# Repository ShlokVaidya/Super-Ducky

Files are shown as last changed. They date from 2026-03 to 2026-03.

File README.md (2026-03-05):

# Super-Ducky
# RP2350A Dual-Mode USB Device

## 1. Description

This project is a custom USB storage and control device powered by the **Raspberry Pi RP2350A** microcontroller. It serves as a dualmode device separating system firmware from user data through a high-speed eMMC interface

The system architecture utilizes a 4-layer PCB to maintain signal integrity for high-speed digital lines (USB and eMMC).

| Component | Function |
| :---- | :---- |
| **RP2350A** | Central MCU handling USB stack and storage logic |
| **eMMC (16GB)** | High density mass storage for user data |
| **QSPI Flash** | Dedicated firmware and bootloader execution |
| **LDO Regulators** | AP2112K series for stable 1.8V and 3.3V rails |
| **USB Mux** | TS3USB221 for signal routing and integrity |

## 2. Why I Built This

I built this project to explore **full stack embedded system development**.

Most beginner projects focus only on firmware or simple microcontroller boards. This project instead focuses on the **entire engineering process** including:

- **Hardware Architecture:** Designing a system that separates firmware execution (QSPI) from high-capacity storage (eMMC).
- **Advanced Sourcing:** Navigating global supply chains to source specialized ICs like the MTFC16GAKAEDQ-AIT eMMC via JLCPCB Global Sourcing.
- **High-Speed Design:** Learning to route differential USB pairs and high-clock-rate storage interfaces on a multi-layer board.
- **Power Management:** Implementing a multi-rail (3.3V/1.8V) system to satisfy different logic level requirements.

The goal was to move beyond hobbyist "breadboarding" and understand how professional-grade embedded products are engineered from the ground up.

## 3. How to Use the Device

1. **Connection:** Connect the device to a computer using a standard USB-C cable.
2. **Standard Operation:** The RP2350A initializes, loads firmware from the QSPI flash, and mounts the eMMC as a storage drive or serial device depending on the firmware configuration.
3. **Boot Selection:** To update firmware or change modes, hold the **Boot Button (GPIO22)** while plugging in the device. This forces the RP2350A into its native USB bootloader mode.
4. **Data Access:** Once connected, the host computer interacts with the 16GB eMMC through the high-speed USB interface managed by the MCU.

## 4. Hardware Visualization

### Full Schematic

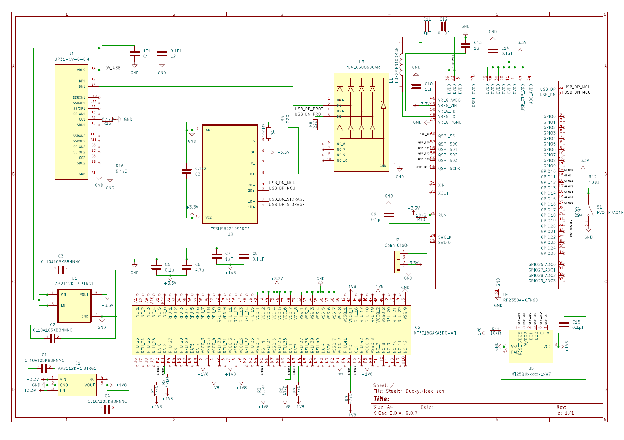
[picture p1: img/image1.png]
Full Schematic


### PCB Layout

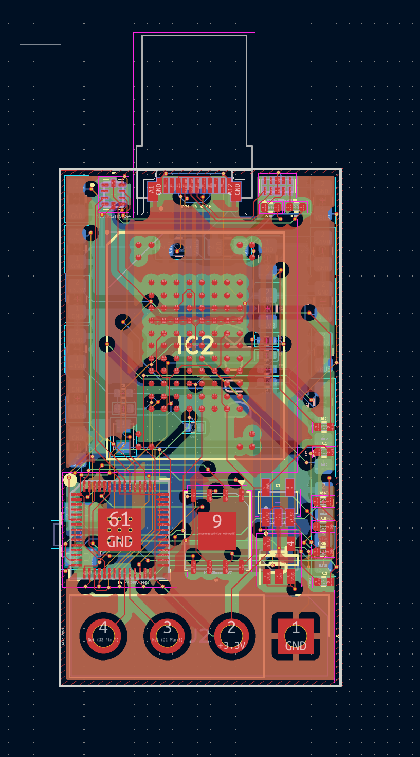
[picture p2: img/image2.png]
PCB Layout


### 3D Render

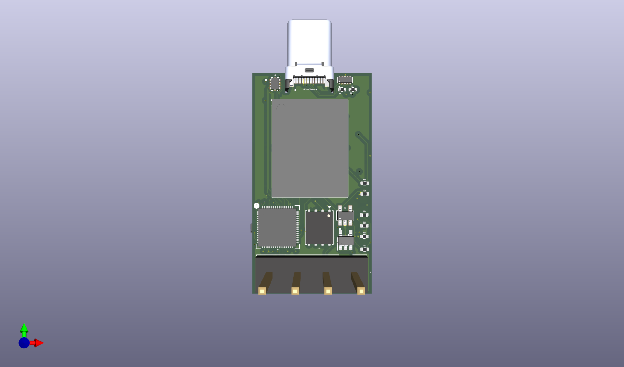
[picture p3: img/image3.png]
3D Render 1

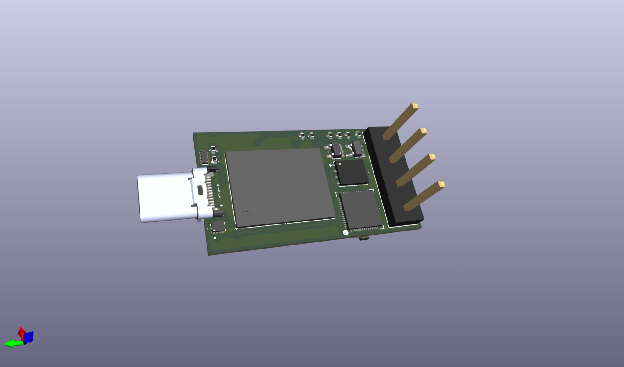
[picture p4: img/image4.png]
3D Render 2

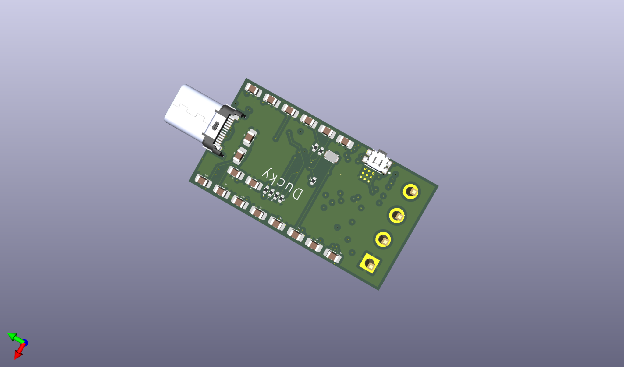
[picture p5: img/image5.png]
3D Render 3

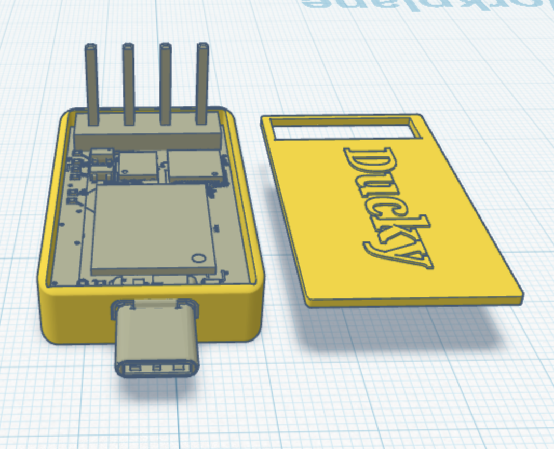
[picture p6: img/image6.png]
3D Render 4


### BOM

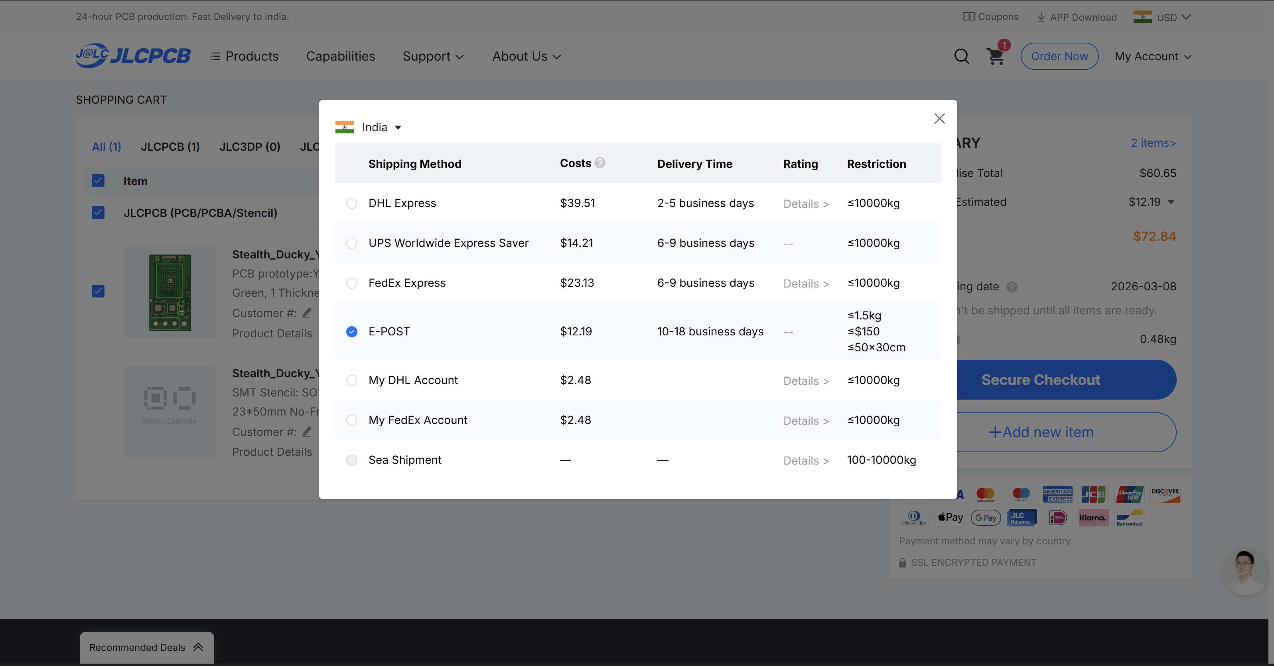
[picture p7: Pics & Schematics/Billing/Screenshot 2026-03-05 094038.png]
JLCPCB

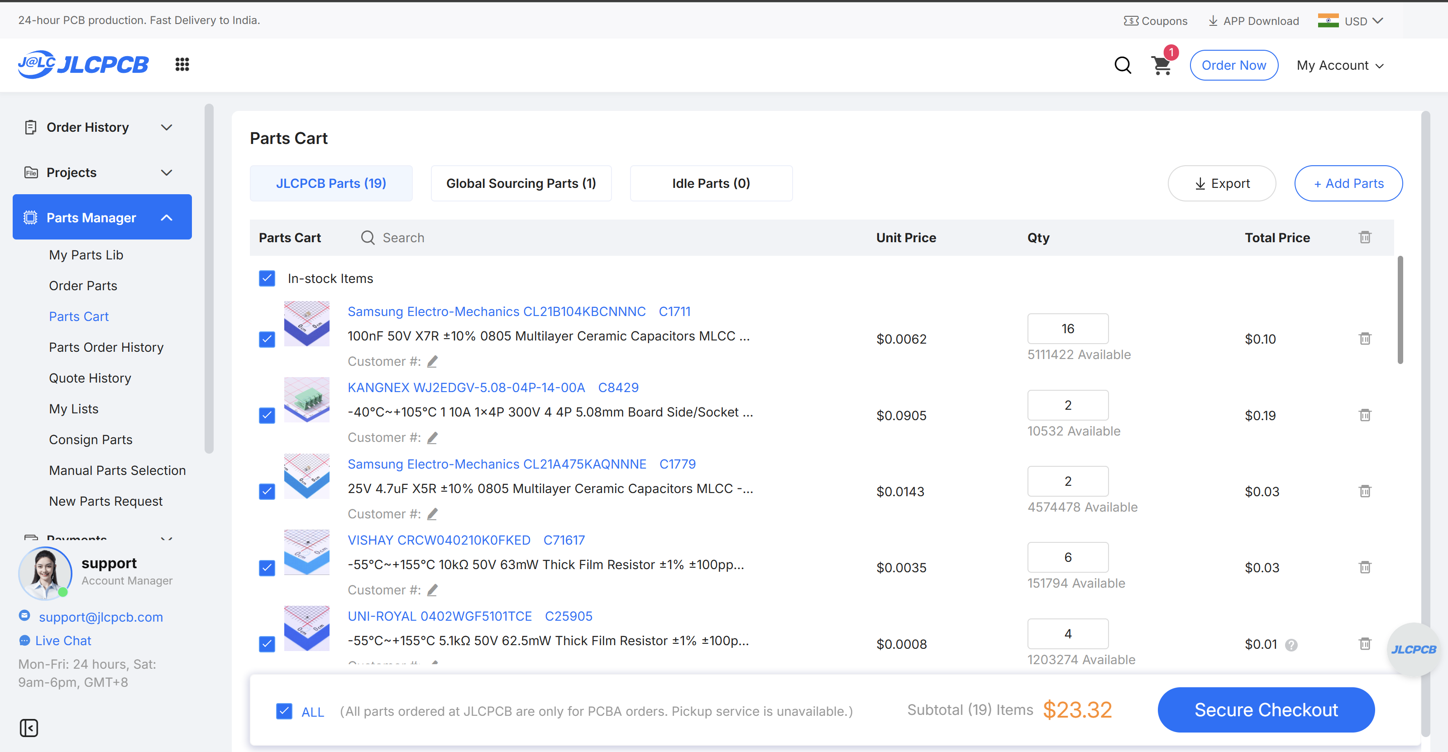
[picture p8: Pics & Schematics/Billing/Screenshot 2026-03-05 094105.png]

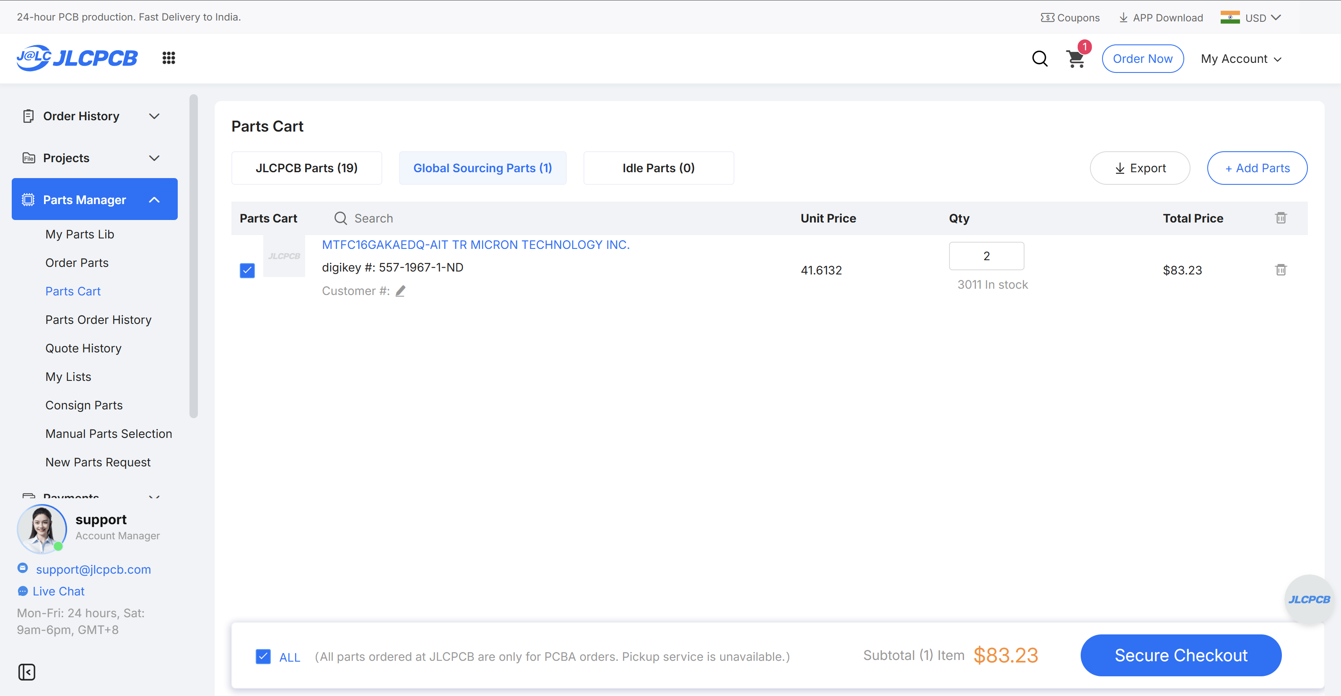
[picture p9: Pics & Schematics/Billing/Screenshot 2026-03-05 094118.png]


## 5. Bill of Materials (BOM)

The following table lists all 20 parts required for the assembly, consolidated from the design files and JLCPCB procurement logs.

| Parts Type | JLCPCB Part \# | MFR Part \# | Link | Description | Unit Price | Qty | Total Price |
| :---- | :---- | :---- | :---- | :---- | :---- | :---- | :---- |
| stock | C1711 | CL21B104KBCNNNC | https://jlcpcb.com/partdetail/2063-CL21B104KBCNNNC/C1711 | 100nF 50V X7R ±10% 0805 Multilayer Ceramic Capacitors MLCC \- SMD/SMT ROHS | 0.0062 | 16 | 0.1 |
| stock | C8429 | WJ2EDGV-5.08-04P-14-00A | https://jlcpcb.com/partdetail/8923-WJ2EDGV\_5\_08\_04P\_1400A/C8429 | \-40℃\~+105℃ 1 10A 1x4P 300V 4 4P 5.08mm Board Side/Socket \- Open Green Hinged (Snap On) Through Hole Plugin,P=5.08mm Pluggable System Terminal Block ROHS | 0.0905 | 2 | 0.19 |
| stock | C1779 | CL21A475KAQNNNE | https://jlcpcb.com/partdetail/2131-CL21A475KAQNNNE/C1779 | 25V 4.7uF X5R ±10% 0805 Multilayer Ceramic Capacitors MLCC \- SMD/SMT ROHS | 0.0143 | 2 | 0.03 |
| buy | C6006988 | UP31-CV-G-CM | https://jlcpcb.com/partdetail/CUI-UP31\_CV\_GCM/C6006988 | \- USB Connectors ROHS | 2.265 | 4 | 9.06 |
| stock | C71617 | CRCW040210K0FKED | https://jlcpcb.com/partdetail/VishayIntertech-CRCW040210K0FKED/C71617 | \-55℃\~+155℃ 10kΩ 50V 63mW Thick Film Resistor ±1% ±100ppm/℃ 0402 Chip Resistor \- Surface Mount ROHS | 0.0035 | 6 | 0.03 |
| buy | C100612 | CR0402JF0220G | https://jlcpcb.com/partdetail/LIZElec-CR0402JF0220G/C100612 | \-55℃\~+125℃ 22Ω 50V 62.5mW Thick Film Resistor ±200ppm/℃ ±5% 0402 Chip Resistor \- Surface Mount ROHS | 0.0003 | 10000 | 3 |
| stock | C25905 | 0402WGF5101TCE | https://jlcpcb.com/partdetail/26648-0402WGF5101TCE/C25905 | \-55℃\~+155℃ 5.1kΩ 50V 62.5mW Thick Film Resistor ±1% ±100ppm/℃ 0402 Chip Resistor \- Surface Mount ROHS | 0.0008 | 4 | 0.01 |
| stock | C25792 | 0402WGF4702TCE | https://jlcpcb.com/partdetail/26535-0402WGF4702TCE/C25792 | \-55℃\~+155℃ 47kΩ 50V 62.5mW Thick Film Resistor ±1% ±100ppm/℃ 0402 Chip Resistor \- Surface Mount ROHS | 0.0008 | 10 | 0.01 |
| stock | C25530 | 0402WGJ0104TCE | https://jlcpcb.com/partdetail/26273-0402WGJ0104TCE/C25530 | \-55℃\~+155℃ 100kΩ 50V 62.5mW Thick Film Resistor ±100ppm/℃ ±5% 0402 Chip Resistor \- Surface Mount ROHS | 0.0006 | 4 | 0.01 |
| stock | C25076 | 0402WGF1000TCE | https://jlcpcb.com/partdetail/25819-0402WGF1000TCE/C25076 | \-55℃\~+155℃ 100Ω 50V 62.5mW Thick Film Resistor ±1% ±100ppm/℃ 0402 Chip Resistor \- Surface Mount ROHS | 0.0008 | 2 | 0.01 |
| stock | C1712 | CL21B105KAFNFNE | https://jlcpcb.com/partdetail/2064-CL21B105KAFNFNE/C1712 | 1uF 25V X7R ±10% 0805 Multilayer Ceramic Capacitors MLCC \- SMD/SMT ROHS | 0.0133 | 18 | 0.24 |
| stock | C138714 | TPD4E05U06DQAR | https://jlcpcb.com/partdetail/TexasInstruments-TPD4E05U06DQAR/C138714 | \-40℃\~+125℃ 0.5pF 10nA 14V 2.5A@8/20us 4 40W@8/20us 5.5V 6.5V ESD IEC 61000-4-2、IEC 61000-4-5、IEC 61000-4-4 Unidirectional USON-10(1x2.5) ESD and Surge Protection (TVS/ESD) ROHS | 0.072 | 2 | 0.15 |
| stock | C295091 | XJHCELNANF-12MHZ | https://jlcpcb.com/partdetail/TAITIENElec-XJHCELNANF12MHZ/C295091 | \-40℃\~+85℃ 12MHz 20pF Crystal Oscillator ±30ppm ±30ppm HC-49S-SMD Crystals ROHS | 0.1385 | 2 | 0.28 |
| stock | C176944 | AP2112K-1.8TRG1 | https://jlcpcb.com/partdetail/DiodesIncorporated-AP2112K\_18TRG1/C176944 | \-40℃\~+85℃@(Ta) 1 1.8V 500mV@(600mA) 50uVrms 55uA 600mA 65dB@(1kHz) 6V Fixed Over Current Protection、Over Temperature Protection、Enable Positive SOT-25 Voltage Regulators \- Linear, Low Drop Out (LDO) Regulators ROHS | 0.1103 | 2 | 0.23 |
| stock | C128396 | TS3USB221ARSER | https://jlcpcb.com/partdetail/TexasInstruments-TS3USB221ARSER/C128396 | \-40℃\~+85℃ 12ns 2.3V\~3.6V 250ps 2:1 30ns 6pF 6Ω 900MHz USB UQFN-10(1.5x2) Analog Switches \- Special Purpose ROHS | 0.2515 | 2 | 0.51 |
| stock | C79167 | EVQP7A01P | https://jlcpcb.com/partdetail/PANASONIC-EVQP7A01P/C79167 | \-20℃\~+70℃ 1.35mm 100,000 cycles 12V 2.2N 3.55mm 3.5mm 50mA PC Pin Rectangular Button SPST Surface Mount, Right Angle SMD,3.6x3.5mm Tactile Switches ROHS | 0.1539 | 2 | 0.31 |
| stock | C42411118 | RP2350A | https://jlcpcb.com/partdetail/RaspberryPi-RP2350A/C42411118 | QFN-60-EP Microcontrollers (MCU/MPU/SOC) ROHS | 1.2406 | 2 | 2.49 |
| stock | C2613930 | W25Q128JVSIM | https://jlcpcb.com/partdetail/WinbondElec-W25Q128JVSIM/C2613930 | \-40℃\~+85℃ 100,000 cycles 10uA 128Mbit 133MHz 150ms@(64KB) 2.7V\~3.6V 20 Years 400us SPI SOIC-8-208mil NOR FLASH ROHS | 3.2212 | 2 | 6.45 |
| stock | C23380830 | AP2112K-3.3TRG1 | https://jlcpcb.com/partdetail/TECHPUBLIC-AP2112K\_33TRG1/C23380830 | \-40℃\~+85℃@(Ta) 1 10uA 3.3V 320mV@(600mA) 5.5V 600mA 75dB@(1kHz) Fixed Over Temperature Protection Positive SOT-23-5 Voltage Regulators \- Linear, Low Drop Out (LDO) Regulators ROHS | 0.1029 | 2 | 0.21 |

| Parts Type | JLCPCB Part \# | Digikey-ID | MFR Part \# | Description | Unit Price | Qty | Total Price |
| :---- | :---- | :---- | :---- | :---- | :---- | :---- | :---- |
| overseas\_shop | C30839157 | digikey \#: 557-1967-1-ND | MTFC16GAKAEDQ-AIT TR | IC FLASH 128GBIT MMC 100LBGA | 41.6132 | 2 | 83.23 |
***

## 6. Billing Summary

Total expenditure for PCB fabrication, assembly, and parts based on project records.

| Category | Cost (INR) | Cost (USD) |
| :---- | :---- | :---- |
| **JLCPCB Assembly (PCBA)** | ₹6,621.82 | $72.84 |
| **Component Sourcing (Global \+ Stock)** | ₹9686.36 | $106.55 |
| **Grand Total** | **₹16308.18** | **$179.39** |

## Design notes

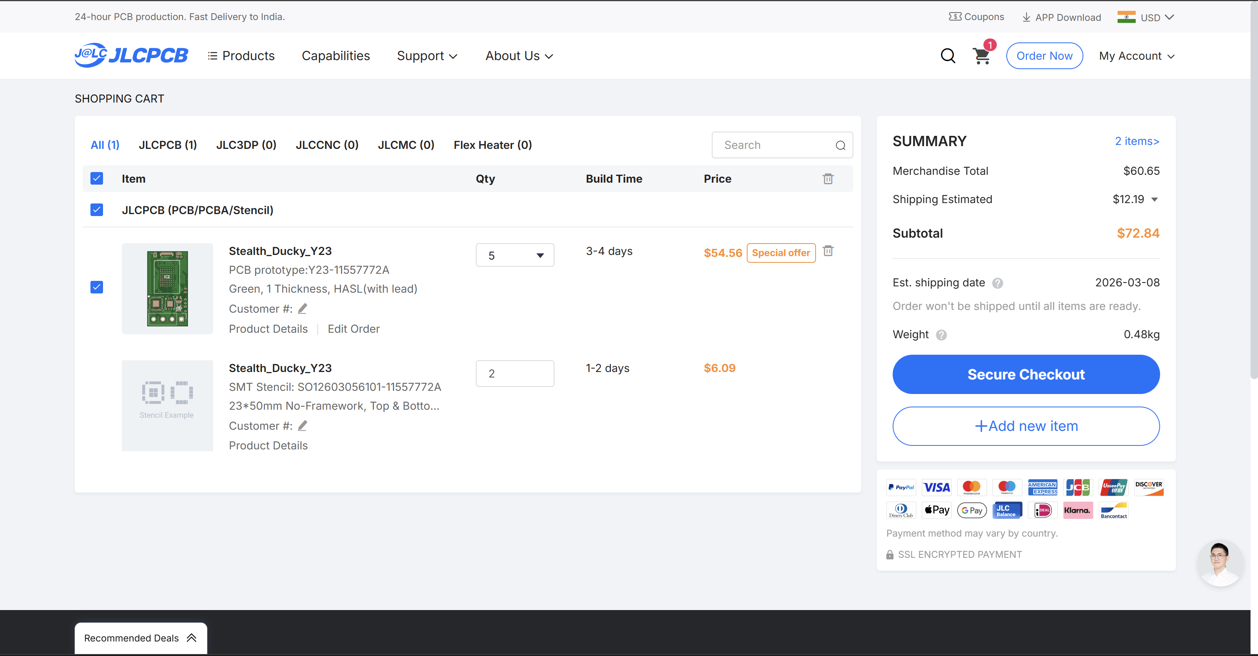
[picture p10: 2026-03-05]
Pics & Schematics/Billing/Screenshot 2026-03-05 094011.png

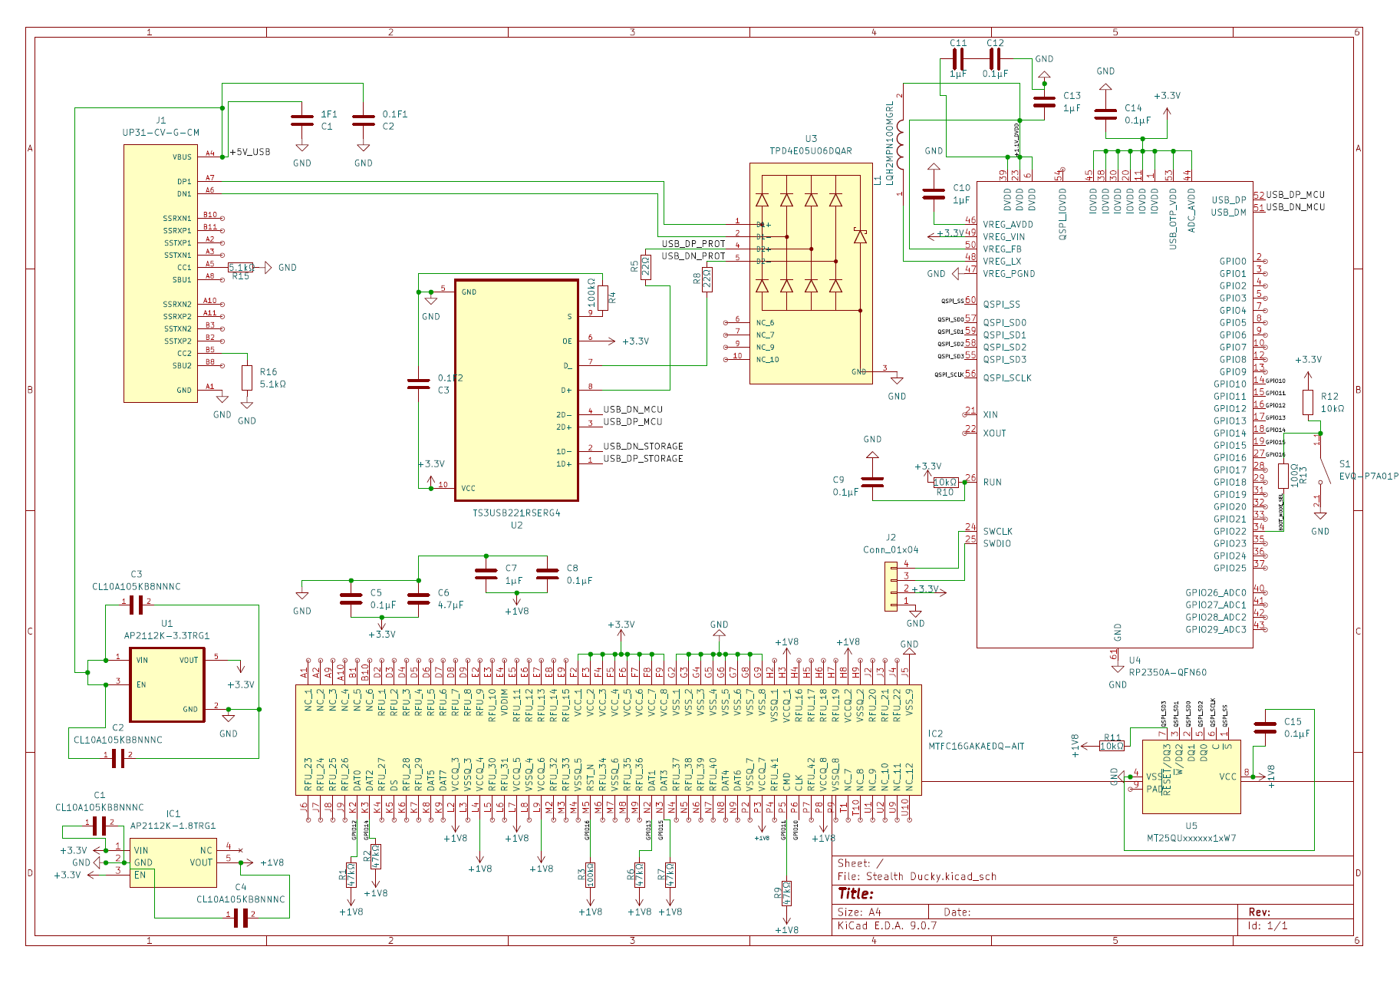
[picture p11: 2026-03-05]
Pics & Schematics/Screenshot 2026-03-05 101711.png

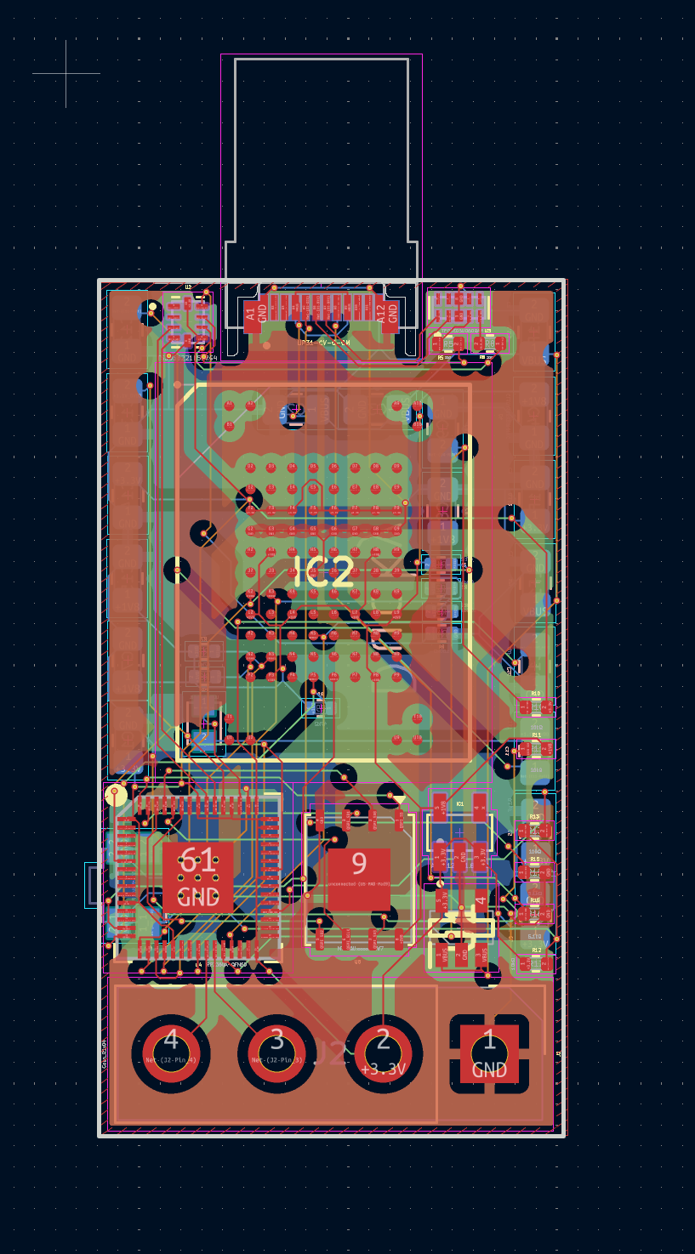
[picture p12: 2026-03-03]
Pics & Schematics/Screenshot 2026-03-02 213854.png

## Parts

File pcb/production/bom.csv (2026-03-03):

Designator | Footprint | Quantity | Value | LCSC Part #
0.1F1 | 0805 | 1 | C2 |  | 5
0.1F2 | 0805 | 1 | C3 |  | 5
1F1 | 0805 | 1 | C1 |  | 5
C1, C2, C3, C4 | 0805 | 4 | CL10A105KB8NNNC |  | 20
C10, C11, C13, C7 | 0805 | 4 | 1µF |  | 20
C12, C14, C15, C5, C8, C9 | 0805 | 6 | 0.1µF |  | 30
C6 | 0805 | 1 | 4.7µF |  | 5
IC1 | SOT95P285X140-5N | 1 | AP2112K-1.8TRG1 |  | 2
IC2 | BGA100C100P10X17_1400X1800X140 | 1 | MTFC16GAKAEDQ-AIT |  | 2
J1 | CUI_UP31-CV-G-CM | 1 | UP31-CV-G-CM |  | 2
J2 | Samtec_HPM-04-01-x-S_Straight_1x04_Pitch5.08mm | 1 | Conn_01x04 |  | 2
L1 | IND_LQH2MPN100MGRL | 1 | LQH2MPN100MGRL |  | 2
R1, R2, R6, R7, R9 | 0402 | 5 | 47kΩ |  | 10
R10, R11, R12 | 0402 | 3 | 10kΩ |  | 6
R13 | 0402 | 1 | 100Ω |  | 2
R15, R16 | 0402 | 2 | 5.1kΩ |  | 4
R3, R4 | 0402 | 2 | 100kΩ |  | 4
R5, R8 | 0402 | 2 | 22Ω |  | 4
S1 | SW_EVQ-P7A01P | 1 | EVQ-P7A01P |  | 2
U1 | SOT95P285X140-5N (2) | 1 | AP2112K-3.3TRG1 |  | 2
U2 | IC_TPD6E001RSER | 1 | TS3USB221RSERG4 |  | 2
U3 | IC_TPD4E05U06DQAR | 1 | TPD4E05U06DQAR |  | 2
U4 | RP2350A_QFN-60_EP_7.75x7.75_Pitch0.4mm | 1 | RP2350A-QFN60 |  | 2
U5 | W-PDFN-8-1EP_6x5mm_P1.27mm_EP3x3mm | 1 | MT25QUxxxxxx1xW7 |  | 2

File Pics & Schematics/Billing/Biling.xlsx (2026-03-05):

Vendor | Price (IN RUPPES) | Price ( IN DOLLARS)
JLCPCBA | 6621.818182 | 72.84
JLC COMPONENTS | 9686.363636 | 106.55
TOTAL |  | 179.39

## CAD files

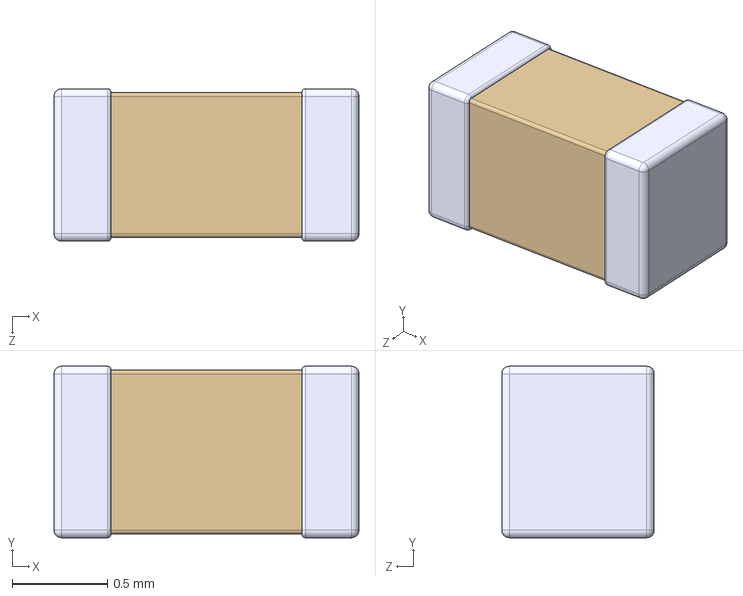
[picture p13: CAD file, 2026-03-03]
3dmodels/CL10A105KB8NNNC.step
1.60 x 0.9 x 0.8 mm

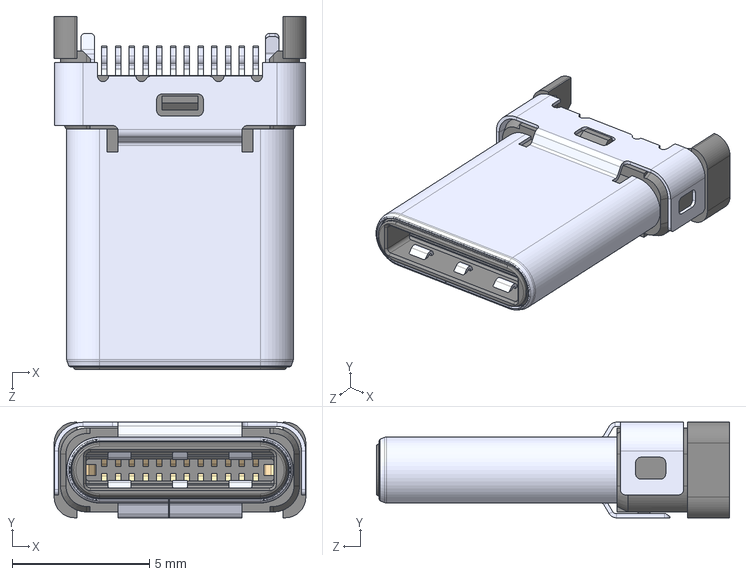
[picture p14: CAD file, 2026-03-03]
3dmodels/UP31-CV-G-CM.step
9.16 x 3.48 x 12.8 mm

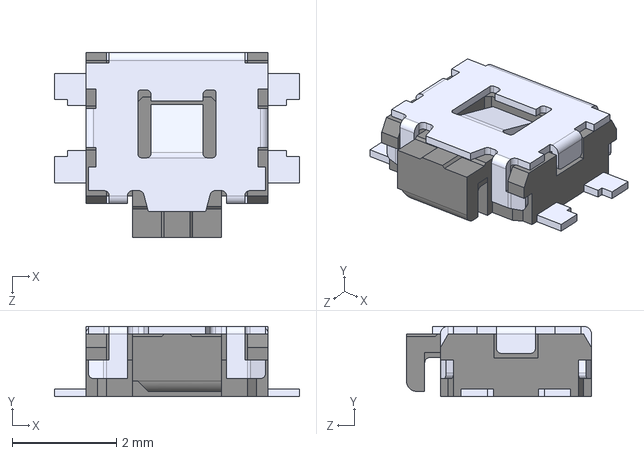
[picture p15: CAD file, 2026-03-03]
3dmodels/EVQ-P7A01P.step
4.70 x 1.35 x 3.55 mm

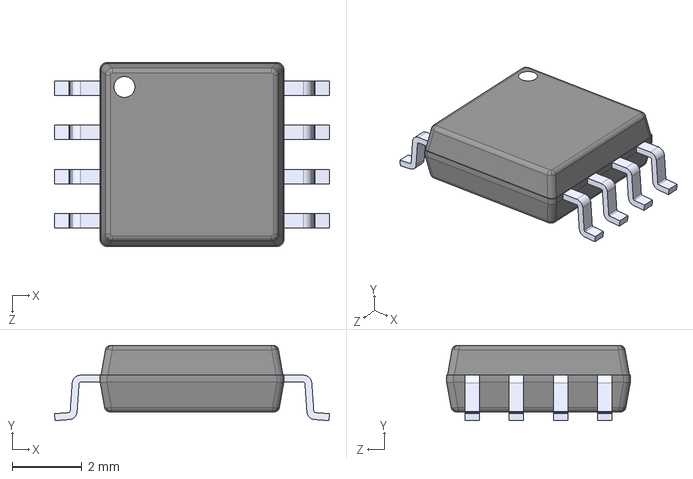
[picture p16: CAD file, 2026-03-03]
3dmodels/W25Q128JVSIM_TR.step
7.90 x 2.16 x 5.28 mm

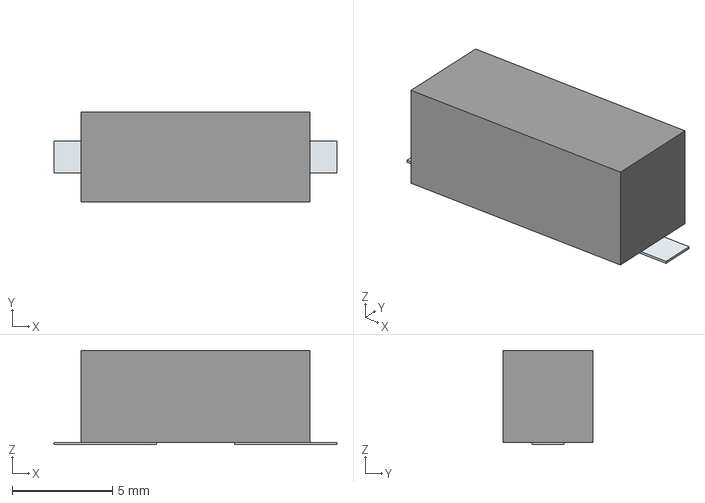
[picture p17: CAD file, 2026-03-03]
3dmodels/XJHCELNANF-12MHZ.stp
14.1 x 4.50 x 4.70 mm
Pins

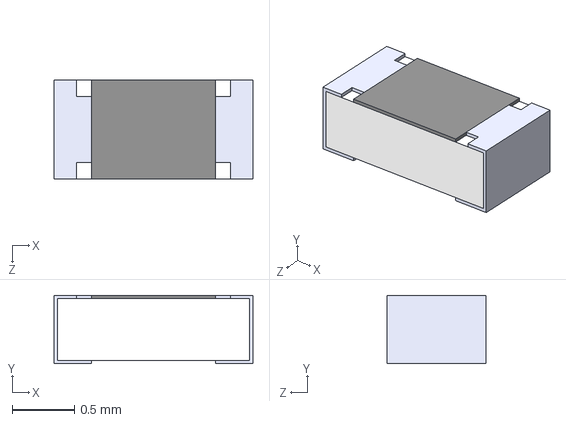
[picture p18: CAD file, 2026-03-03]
3dmodels/0603WAF1002T5E.step
1.60 x 0.55 x 0.8 mm

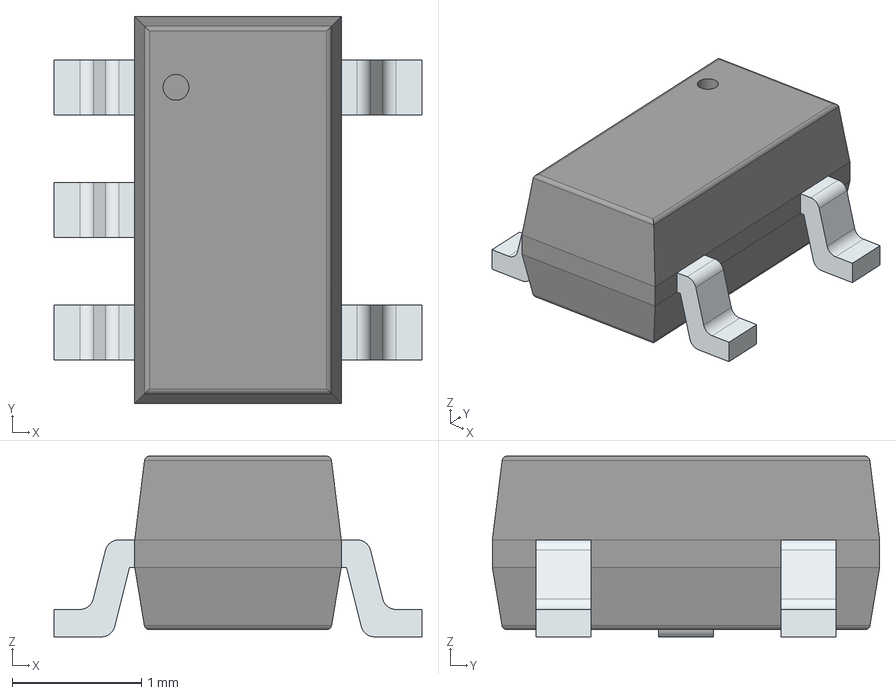
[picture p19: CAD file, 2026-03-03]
3dmodels/AP2112K-1.8TRG1.stp
2.85 x 3.00 x 1.40 mm
PinsArrayL
PinsArrayR

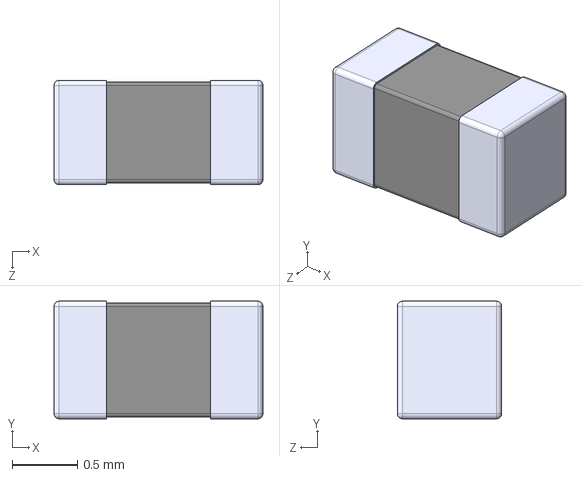
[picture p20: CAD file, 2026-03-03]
3dmodels/CC0603KRX7R9BB104.step
1.60 x 0.9 x 0.8 mm

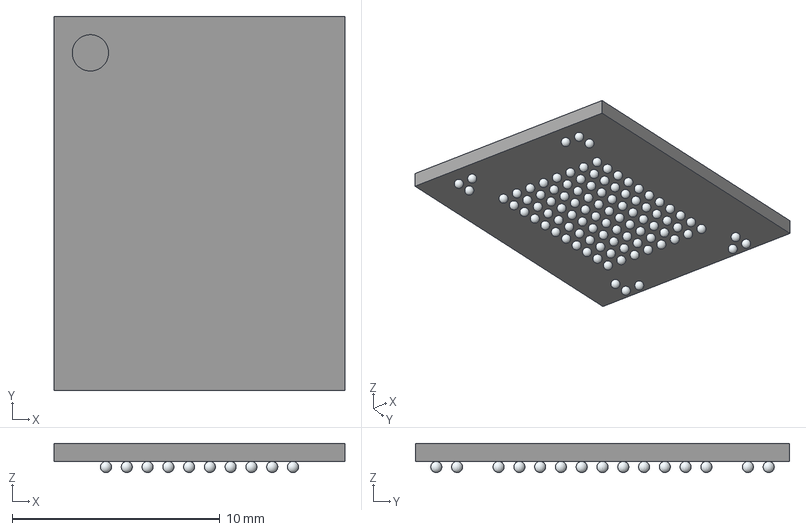
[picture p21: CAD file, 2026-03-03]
3dmodels/MTFC16GAKAEDQ-AIT.stp
14.0 x 18.0 x 1.40 mm
A1
A2
A9
A10
B1
B10
D2
D3
D4
D5
D6
D7
D8
D9
E2
E3
E4
E5
E6
E7
E8
E9
F2
F3
F4
F5
F6
F7
F8
F9
G2
G3
G4
G5
G6
G7
G8
G9
H2
H3
H4
H5
H6
H7
H8
H9
J2
J3
J4
J5
J6
J7
J8
J9
K2
K3
K4
K5
K6
K7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

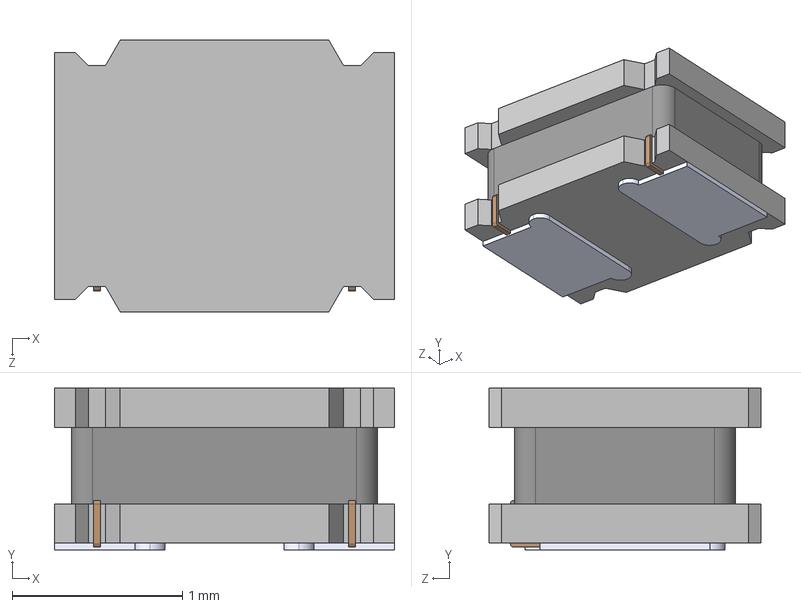
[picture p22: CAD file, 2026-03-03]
3dmodels/LQH2MPN100MGRL.step
2.00 x 0.95 x 1.60 mm

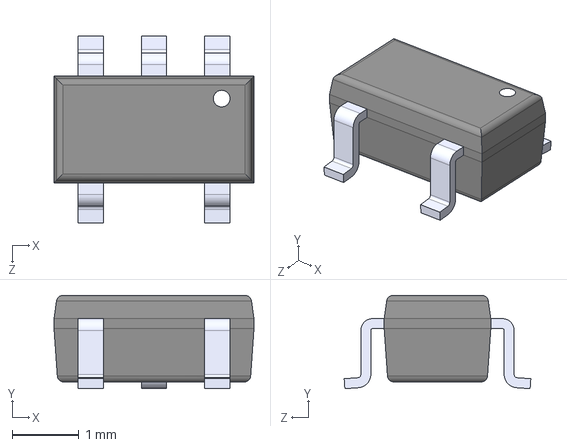
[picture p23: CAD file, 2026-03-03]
3dmodels/AP2112K-3.3TRG1.step
3.00 x 1.40 x 2.80 mm

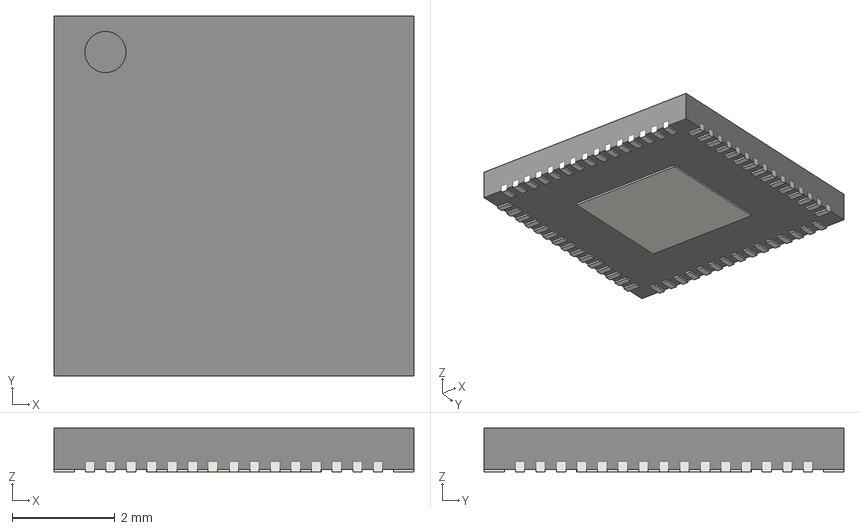
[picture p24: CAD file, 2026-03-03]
3dmodels/RP2350A-QFN60.step
7.00 x 7.00 x 0.85 mm

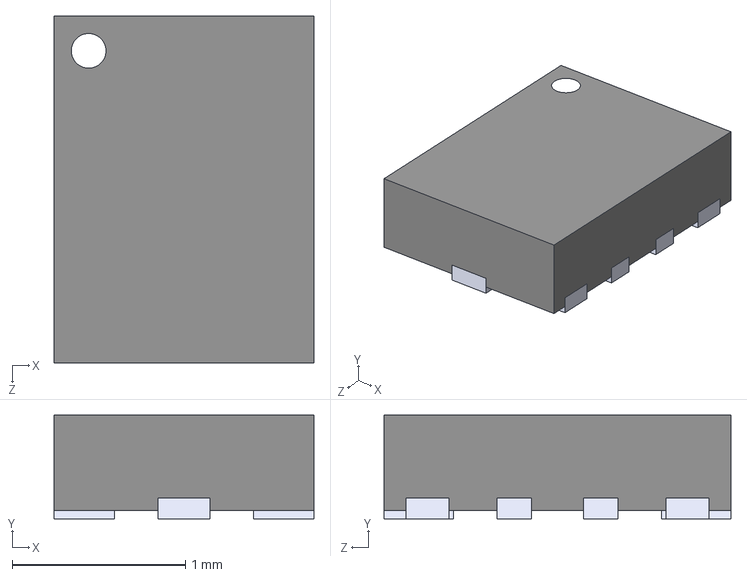
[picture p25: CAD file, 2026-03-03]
3dmodels/TS3USB221RSERG4.step
1.50 x 0.6 x 2.00 mm

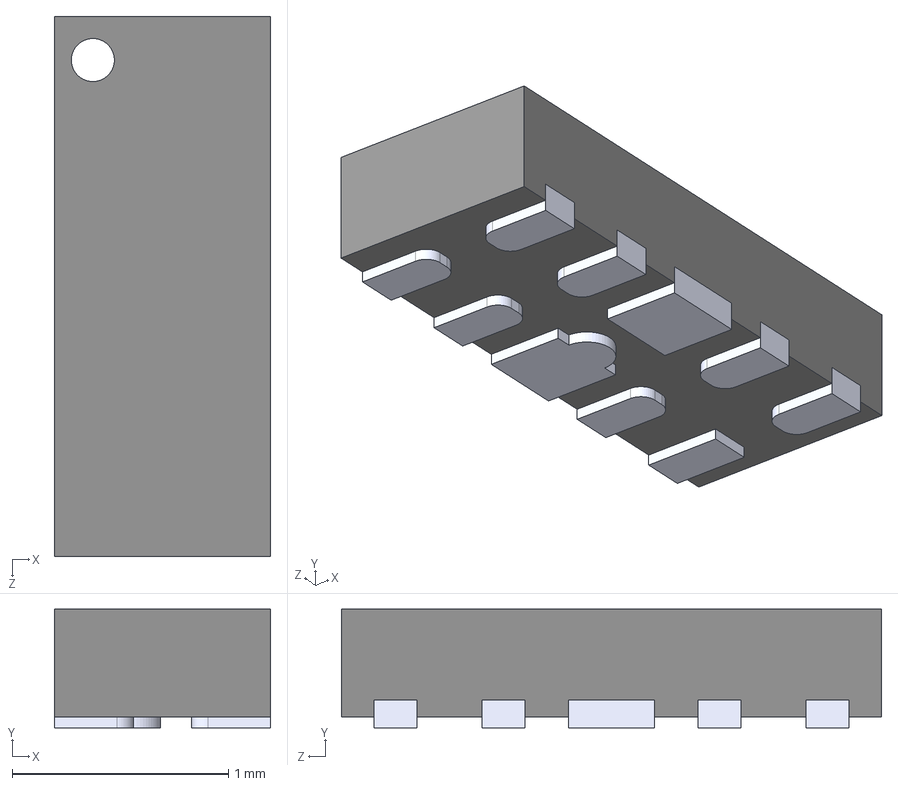
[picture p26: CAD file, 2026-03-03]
3dmodels/TPD4E05U06DQAR.step
1.00 x 0.55 x 2.50 mm

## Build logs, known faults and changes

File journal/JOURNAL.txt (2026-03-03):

day one stuff

so the project is about making a custom RP2350A dual-mode USB device with native eMMC storage. First thing i had to do was figure out the memry architecure cause the RP2350A actually needs external flash to run firmware. i looked at option A which was using just one QSPI flash for everything but i rejected it.
      Option B was a split architecure where QSPI flash is for firmware and eMMC is for mass storage, and i picked this cause its a professional pattern where firmware stays isolated. Then i had to plan the voltage domains which was super critical.
  The core is 1.1V and eMMC uses 3.3V for VCC and 1.8V for VCCQ in high speed mode. This meant i needed a separate 1.8V LDO and careful routing. If I accidentaly connected 3.3V to the 1.8V flash IOVDD it would permantly destroy the flash. ChatGPT helped me validate this huge risk.
        For the USB interface i chose USB-C for modern compatiblity and it needs 5.1kΩ pull-down resistors on CC1 and CC2. ChatGPT confirmed i need independent CC resistors and def shouldn't short them together. A critical realiztion was that the RP2350A does NOT have an SDMMC peripherel.
That means i gotta implement the MMC protocol via PIO and use a 4-bit data bus and handle the initialization sequence. This totally changed the project from just hardware into hardware and low-level firmware engineering. For power i chose AP2112K LDOs for 3.3V and 1.8V cause they have low noise and are simple to implement.

day to: scematics

Moving on to schematic design, the RP2350 internal SMPS needed an external inductor. Originally I picked a 10µH inductor but it got flagged later that the recommended value is lower. If the inductor is too large it causes poor transient response and instability. So yeah, that got corrected.
   My decoupling stratgy was putting a 0.1µF local capacitor and a 4.7µF bulk capacitor to minimize ground bounce and voltage droop. I made sure the QSPI flash IOVDD was only tied to 1.8V. For the eMMC wiring i connected CMD, CLK, and DAT0-DAT3 and added pull-ups because MMC requires a defined bus state.
         ChatGPT confirmed my bus termination approach was right. For USB protection I added TPD4E05 ESD protection and made a critical note to not create stubs before the ESD. I also designed a boot mode button with a 10k pull-up to 3.3V connected to GPIO22. Even though internal pull-ups exist, a hardware pull-up is way safer for a stable boot mode. This basically ensures deterministic boot selection at reset.

third day pcb

      For the layer stack I chose a 4-layer setup. This gives better return path control and stable USB routing. The SMPS loop area was minimized between the inductor, switching node, and output capacitor to reduce EMI.
  I placed the decoupling capacitors as close as physicaly possible with a direct via to the ground plane.

forth day encosure & firmware

I designed a 3D enclosure with a USB-C cutout and button clearance cause mechanical integration really affects usability and durability. Then I planned out a layered firmware model that goes from TinyUSB to MSC to Block Device to MMC Protocol to PIO Transport.
      Making it layered makes it way easier for debugging and maintainability. The eMMC initialization sequence requires a bunch of commands like CMD0, CMD1, CMD2, CMD3, CMD7, and CMD6 plus CRC calculations.
  Just to b clear, ChatGPT was used as a technical review assistant but it did NOT auto-generate the final PCB or perform independent design decisions. All the engineering decisions were totally made by me.
            Overall this project expanded my understanding of multi-rail embedded power systems and native MMC protocol. The final status is a complete schematic, complete PCB layout, and complete enclosure design ready for fabrication.

exact parts i used for the build

    so to b super specific about the hardware, here is the exact parts i slaped on the board. the main brain is obviously the RP2350A-QFN60. for the usb connector i went with UP31-CV-G-CM and protected the data lines using the TPD4E05U06DQAR esd chip.
   I also used a TS3USB221RSERG4 usb switch in there. for the main mass storage eMMC i used the MTFC16GAKAEDQ-AIT. but wait there is actually a different storage for HID scripts which is the MT25QUxxxxxx1xW7 QSPI flash.
        to activate that HID mode on the different storage I put in a EVQ-P7A01P tactile button so you can switch it up. for the power stuff I used AP2112K-3.3TRG1 and AP2112K-1.8TRG1 LDOs. Oh and that 10µH inductor I mentioned on day 2 that was maybe too big? the part number for that one was LQH2MPN100MGRL.

            Overall this project expanded my understanding of multi-rail embedded power systems and native MMC protocol. The final status is a complete schematic, complete PCB layout, and complete enclosure design ready for fabrication.

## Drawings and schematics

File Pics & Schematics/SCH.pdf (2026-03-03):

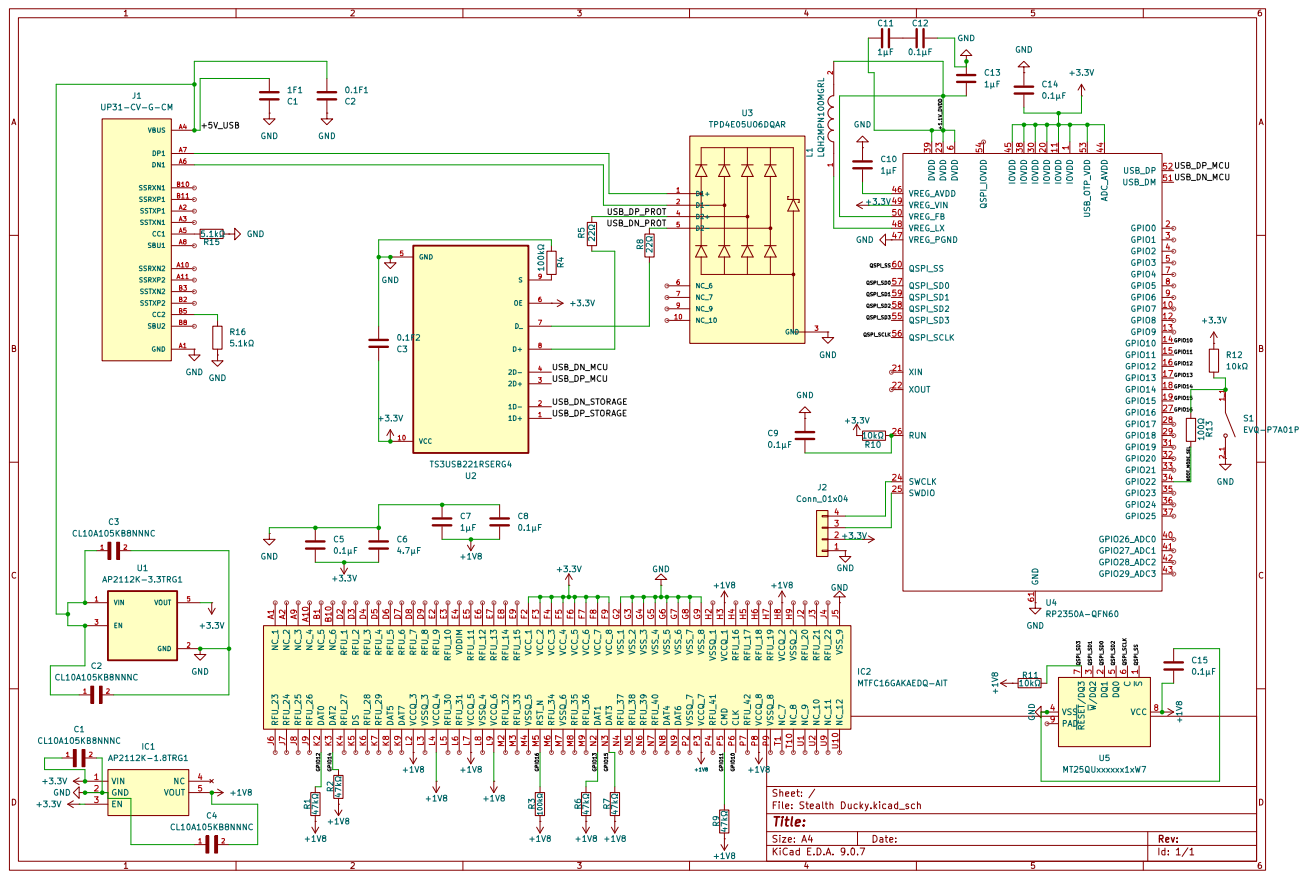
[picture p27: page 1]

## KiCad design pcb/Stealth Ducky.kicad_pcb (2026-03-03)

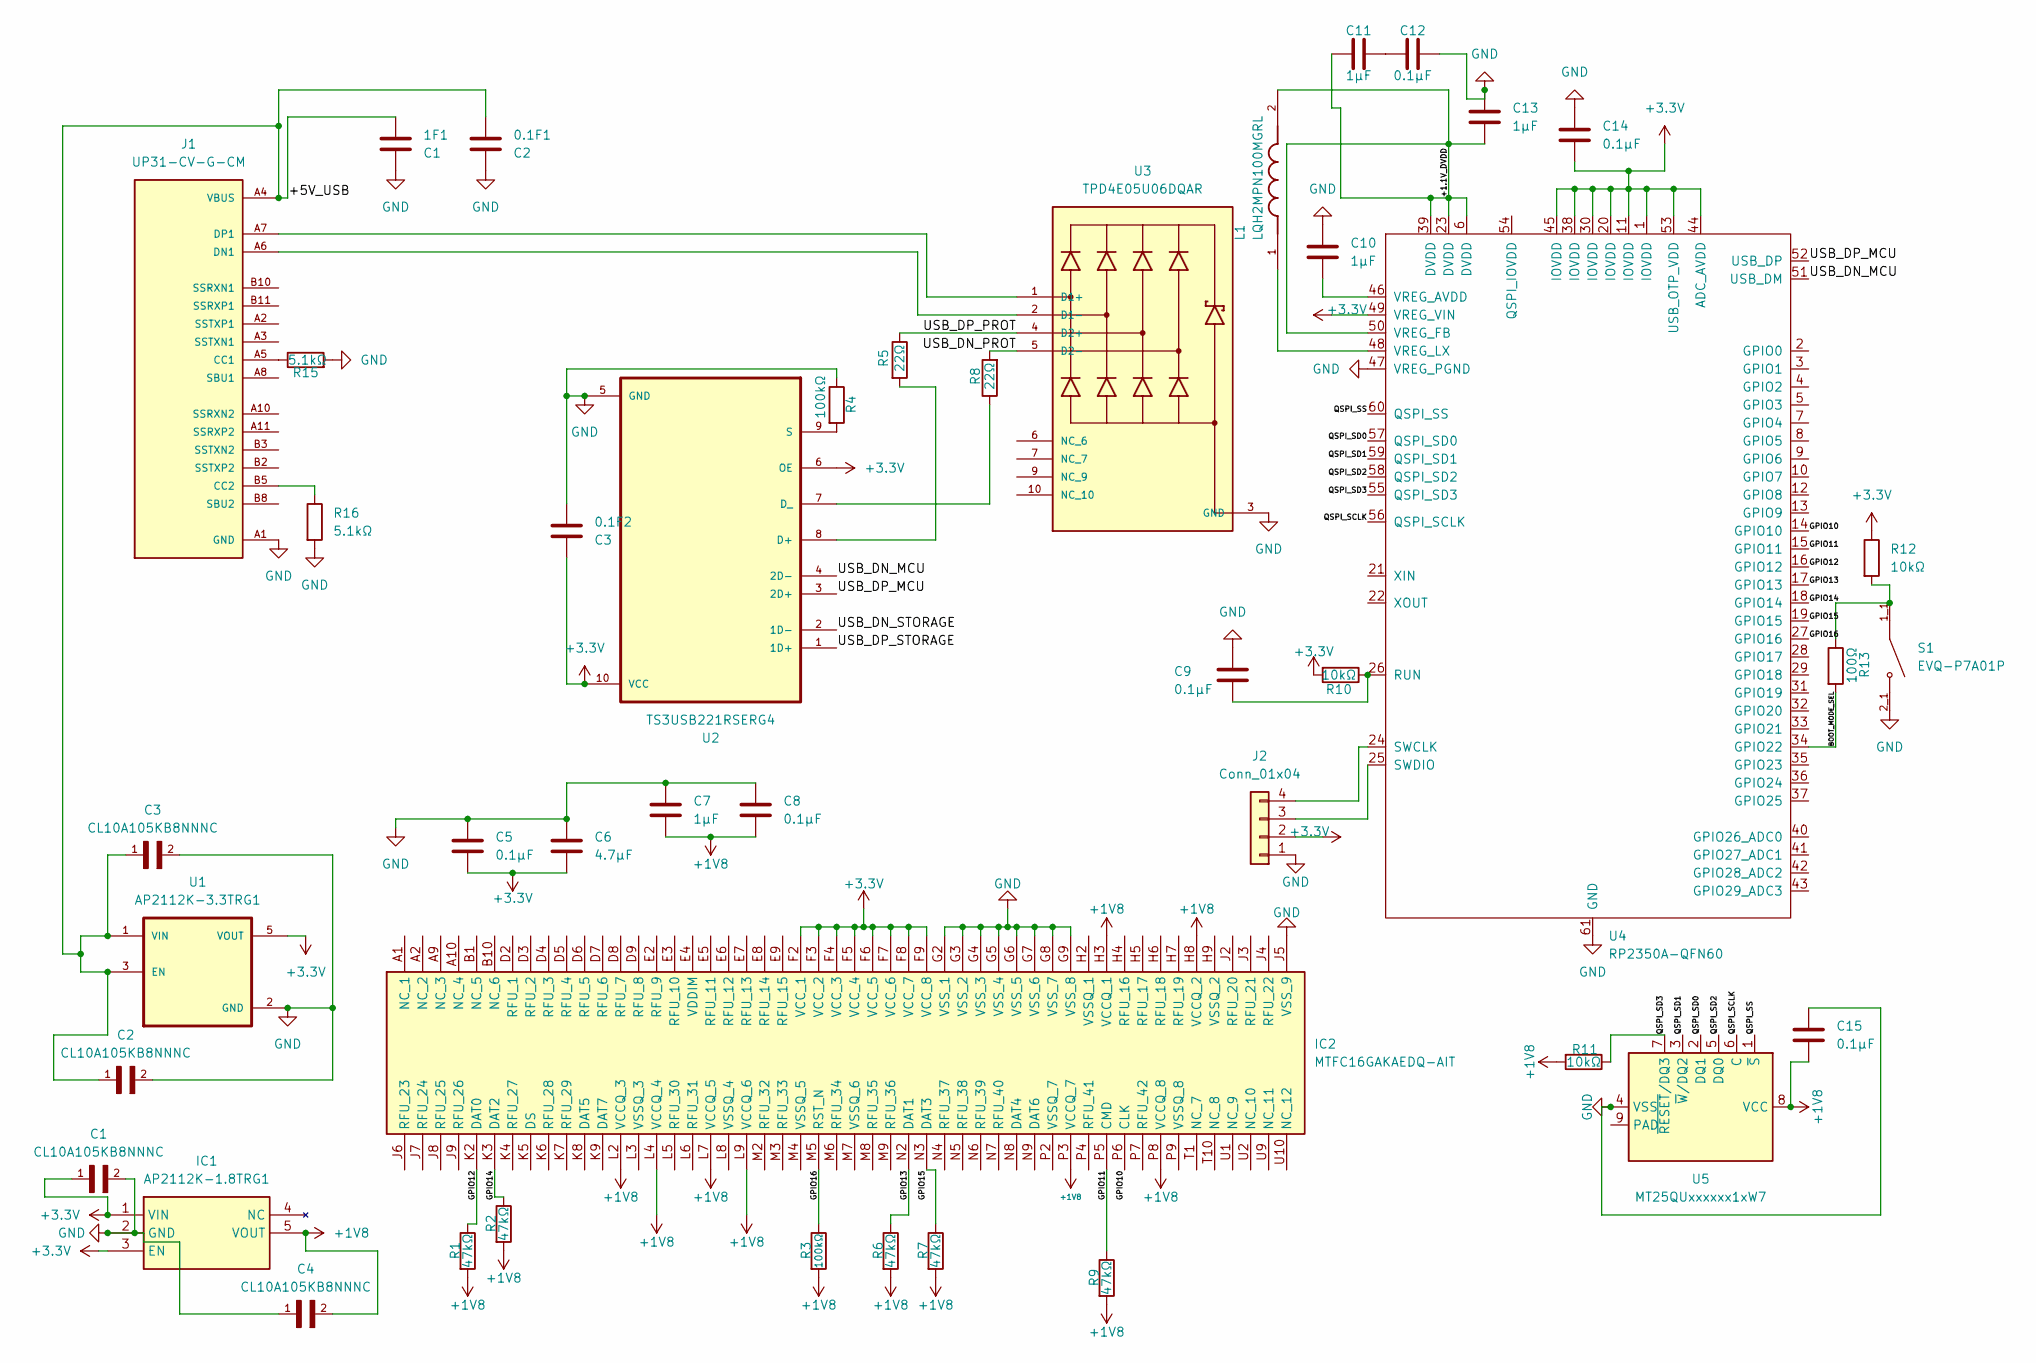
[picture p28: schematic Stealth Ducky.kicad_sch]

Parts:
0.1F1: C2; C_0805_2012Metric_Pad1.18x1.45mm_HandSolder
0.1F2: C3; C_0805_2012Metric_Pad1.18x1.45mm_HandSolder
1F1: C1; C_0805_2012Metric_Pad1.18x1.45mm_HandSolder
C1, C2, C3, C4: CL10A105KB8NNNC; C_0805_2012Metric_Pad1.18x1.45mm_HandSolder
C5, C8, C9, C12, C14, C15: 0.1µF; C_0805_2012Metric_Pad1.18x1.45mm_HandSolder
C6: 4.7µF; C_0805_2012Metric_Pad1.18x1.45mm_HandSolder
C7, C10, C11, C13: 1µF; C_0805_2012Metric_Pad1.18x1.45mm_HandSolder
IC1: AP2112K-1.8TRG1; SOT95P285X140-5N; Manufacturer_Part_Number AP2112K-1.8TRG1; Mouser Part Number 621-AP2112K-1.8TRG1
IC2: MTFC16GAKAEDQ-AIT; BGA100C100P10X17_1400X1800X140; Manufacturer_Part_Number MTFC16GAKAEDQ-AIT; Mouser Part Number 340-274027-TRAY
J1: UP31-CV-G-CM; CUI_UP31-CV-G-CM; PARTREV 1.04
J2: Conn_01x04; Samtec_HPM-04-01-x-S_Straight_1x04_Pitch5.08mm
L1: LQH2MPN100MGRL; IND_LQH2MPN100MGRL; PARTREV N/A
R1, R2, R6, R7, R9: 47kΩ; R_0402_1005Metric
R3, R4: 100kΩ; R_0402_1005Metric
R5, R8: 22Ω; R_0402_1005Metric
R10, R11, R12: 10kΩ; R_0402_1005Metric
R13: 100Ω; R_0402_1005Metric
R15, R16: 5.1kΩ; R_0402_1005Metric
S1: EVQ-P7A01P; SW_EVQ-P7A01P; PARTREV 2022.4
U1: AP2112K-3.3TRG1; SOT95P285X140-5N (2); PARTREV 2-2
U2: TS3USB221RSERG4; IC_TPD6E001RSER
U3: TPD4E05U06DQAR; IC_TPD4E05U06DQAR; PARTREV N
U4: RP2350A-QFN60; RP2350A_QFN-60_EP_7.75x7.75_Pitch0.4mm
U5: MT25QUxxxxxx1xW7; W-PDFN-8-1EP_6x5mm_P1.27mm_EP3x3mm

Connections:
+1V8: C4.2, C7.1, C8.1, C15.1, IC1.5 (VOUT), IC2.H3 (VCCQ_1), IC2.H8 (VCCQ_2), IC2.L2 (VCCQ_3), IC2.L4 (VCCQ_4), IC2.L7 (VCCQ_5), IC2.L9 (VCCQ_6), IC2.P3 (VCCQ_7), IC2.P8 (VCCQ_8), R1.2, R2.2, R3.2, R6.2, R7.2, R9.2, R11.2, U5.8 (VCC)
+3.3V: 0.1F2.1, C1.1, C5.1, C6.1, C14.2, IC1.1 (VIN), IC1.3 (EN), IC2.F2 (VCC_1), IC2.F3 (VCC_2), IC2.F4 (VCC_3), IC2.F5 (VCC_4), IC2.F6 (VCC_5), IC2.F7 (VCC_6), IC2.F8 (VCC_7), IC2.F9 (VCC_8), J2.2, R10.2, R12.1, U1.5 (VOUT), U2.6 (OE), U2.10 (VCC), U4.1 (IOVDD), U4.11 (IOVDD), U4.20 (IOVDD), U4.30 (IOVDD), U4.38 (IOVDD), U4.44 (ADC_AVDD), U4.45 (IOVDD), U4.49 (VREG_VIN), U4.53 (USB_OTP_VDD)
/+1.1V_DVDD: C11.2, C13.2, L1.2, U4.6 (DVDD), U4.23 (DVDD), U4.39 (DVDD), U4.50 (VREG_FB)
/BOOT_MODE_SEL: R13.2, U4.34 (GPIO22)
/GPIO10: IC2.P6 (CLK), U4.14 (GPIO10)
/GPIO11: IC2.P5 (CMD), R9.1, U4.15 (GPIO11)
/GPIO12: IC2.K2 (DAT0), R1.1, U4.16 (GPIO12)
/GPIO13: IC2.N2 (DAT1), R6.1, U4.17 (GPIO13)
/GPIO14: IC2.K3 (DAT2), R2.1, U4.18 (GPIO14)
/GPIO15: IC2.N3 (DAT3), R7.1, U4.19 (GPIO15)
/GPIO16: IC2.M5 (RST_N), R3.1, U4.27 (GPIO16)
/QSPI_SCLK: U4.56 (QSPI_SCLK), U5.6 (C)
/QSPI_SD0: U4.57 (QSPI_SD0), U5.2 (DQ1)
/QSPI_SD1: U4.59 (QSPI_SD1), U5.3 (~W/DQ2)
/QSPI_SD2: U4.58 (QSPI_SD2), U5.5 (DQ0)
/QSPI_SD3: R11.1, U4.55 (QSPI_SD3), U5.7 (~RESET/DQ3)
/QSPI_SS: U4.60 (QSPI_SS), U5.1 (~S)
/USB_DN_MCU: U2.4 (2D-), U4.51 (USB_DM)
/USB_DN_PROT: R8.2, U3.5 (D2-)
/USB_DN_STORAGE: U2.2 (1D-)
/USB_DP_MCU: U2.3 (2D+), U4.52 (USB_DP)
/USB_DP_PROT: R5.1, U3.4 (D2+)
/USB_DP_STORAGE: U2.1 (1D+)
GND: 0.1F1.2, 0.1F2.2, 1F1.2, C1.2, C2.2, C3.2, C4.1, C5.2, C6.2, C7.2, C8.2, C9.1, C10.1, C12.1, C13.1, C14.1, C15.2, IC1.2 (GND), IC2.G2 (VSS_1), IC2.G3 (VSS_2), IC2.G4 (VSS_3), IC2.G5 (VSS_4), IC2.G6 (VSS_5), IC2.G7 (VSS_6), IC2.G8 (VSS_7), IC2.G9 (VSS_8), IC2.J5 (VSS_9), J1.A1 (GND), J1.A12 (GND), J1.B1 (GND), J1.B12 (GND), J2.1, R4.1, R15.2, R16.2, S1.2_1, S1.2_2, U1.2 (GND), U2.5 (GND), U3.3 (GND), U3.8 (GND), U4.47 (VREG_PGND), U4.61 (GND), U5.4 (VSS)
unnamed: C11.1, C12.2
unnamed: J1.A5 (CC1), R15.1
unnamed: J1.B5 (CC2), R16.1
unnamed: J1.A6 (DN1), U3.2 (D1-)
unnamed: J1.A7 (DP1), U3.1 (D1+)
unnamed: J2.3, U4.25 (SWDIO)
unnamed: J2.4, U4.24 (SWCLK)
unnamed: R12.2, R13.1, S1.1_1, S1.1_2
unnamed: R5.2, U2.8 (D+)
unnamed: R8.1, U2.7 (D_)
unnamed: R4.2, U2.9 (S)
unnamed: C9.2, R10.1, U4.26 (RUN)
unnamed: C10.2, U4.46 (VREG_AVDD)
unnamed: L1.1, U4.48 (VREG_LX)
VBUS: 0.1F1.1, 1F1.1, C2.1, C3.1, J1.A4 (VBUS), J1.A9 (VBUS), J1.B4 (VBUS), J1.B9 (VBUS), U1.1 (VIN), U1.3 (EN)

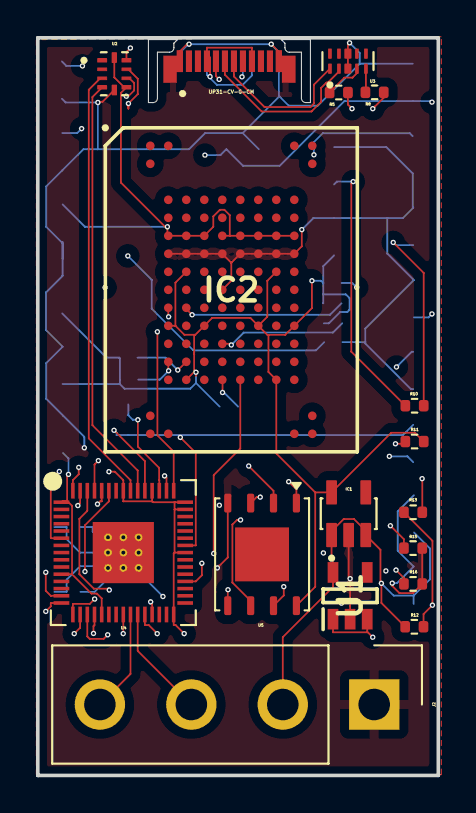
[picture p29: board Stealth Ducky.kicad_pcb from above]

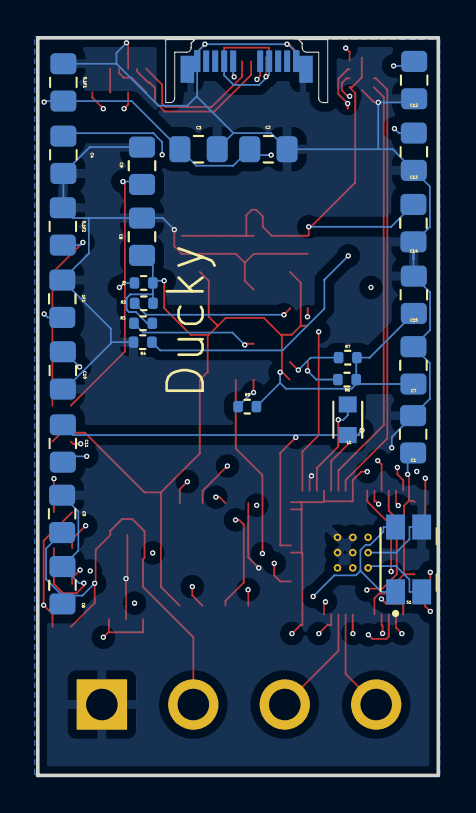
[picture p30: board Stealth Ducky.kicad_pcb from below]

Board: 4 copper layers, 22.2 x 41.0 mm, 44 parts (27 on the bottom side), 37 nets.

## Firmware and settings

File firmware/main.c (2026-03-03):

#include "pico/stdlib.h"
#include "bsp/board.h"
#include "tusb.h"

#define BOOT_MODE_PIN 22

bool hid_mode = false;

int main(void)
{
    board_init();

    gpio_init(BOOT_MODE_PIN);
    gpio_set_dir(BOOT_MODE_PIN, GPIO_IN);
    gpio_pull_up(BOOT_MODE_PIN);

    sleep_ms(10);

    hid_mode = (gpio_get(BOOT_MODE_PIN) == 0);

    tusb_init();

    while (1)
    {
        tud_task();
    }
}
